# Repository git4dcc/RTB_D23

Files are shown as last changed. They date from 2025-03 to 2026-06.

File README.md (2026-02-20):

# RTB_D23




The D23 decoder is a double sided mobile decoder with 8-pol NEM 652 connector. The decoder is designed to integrate into the [RTB](https://rtb4dcc.de/concept/) digital control infrastructure.

<details>
<summary>See also</summary>

- [RTB_D12 - custom](/../../../../git4dcc/RTB_D12) (Fleischmann V100)
- [RTB_D13 - custom](/../../../../git4dcc/RTB_D13) (Minitrix coach)
- [RTB_D15 - custom](/../../../../git4dcc/RTB_D15) (Minitrix V160)
- [RTB_D16 - NEM651](/../../../../git4dcc/RTB_D16)
- [RTB_D20 - NEM651](/../../../../git4dcc/RTB_D20)
- [RTB_D21 - Next18](/../../../../git4dcc/RTB_D21)
- [RTB_D22 - Plux16](/../../../../git4dcc/RTB_D22)

</details>

<details>
<summary>User Guides</summary>

- User Guide - DE
- [User Guide - EN](https://rtb4dcc.de/rtb_decoder_reference_en/)

</details>

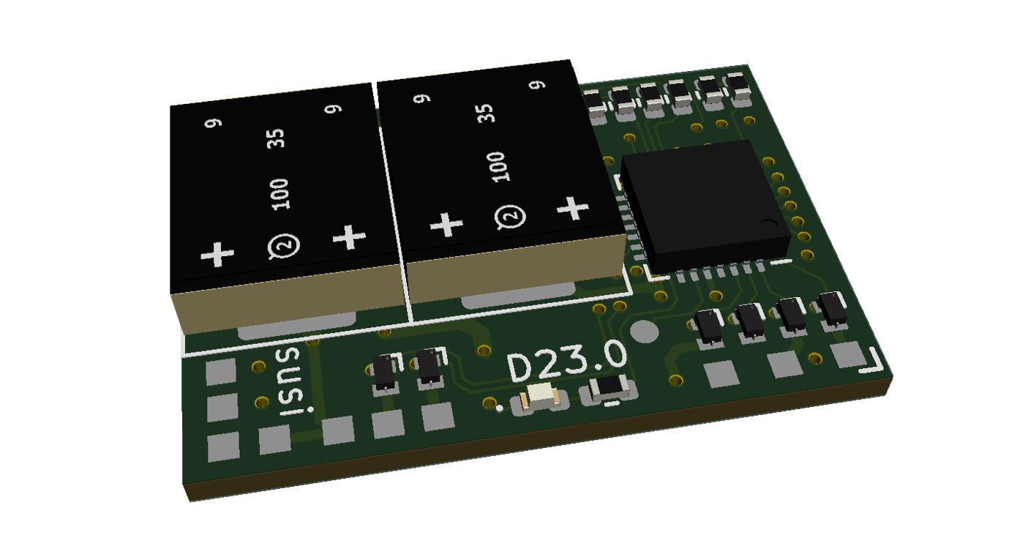
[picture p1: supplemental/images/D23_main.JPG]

<br>

## Decoder features,
- **NEM 652** connector
- **DCC**
  - DCC-A automatic logon
  - DCC-R protocol extension
  - Service Mode Programming
- **Railcom**
  - Channel 1/2
  - POM, xPOM
  - DYN: Speed, QoS, Track-voltage, Motor-current, AUX-current, Temp, Distance travelled
- Double sided
- Dimension: 19 x 12 mm
- 7-28V track voltage
- heartbeat LED
- adjustable max motor current (default 500mA)
- adjustable max AUX current (default 500mA)
- over temp protection
- Function output: LF/LR (dimmable, 1.4kHz) open drain
- Function output: AUX1 (dimmable, 1.4kHz) open drain via NEM 652 connector
- Function output: AUX2/AUX3/AUX4 open drain via solder pads
- Function output: AUX5/AUX6 logic level (3.3V) or ZBCLK/ZBDAT (3.3V)
- onboard buffer capacitor (2x 100uF/35V)
- <10mA idle power consumption
- Firmware update over main tracks via DCC-R protocol

# Hardware
The current PCB layout uses SMD footprints with 0.5mm pitch and 0402 parts. Reflow soldering is mandatory whereas handsoldering near to impossible.

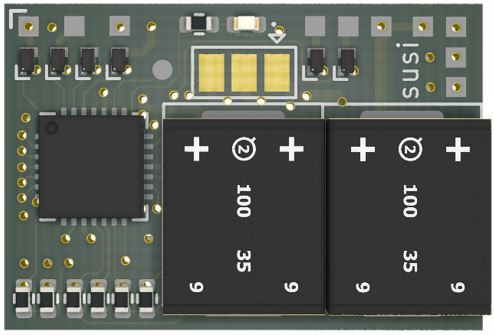
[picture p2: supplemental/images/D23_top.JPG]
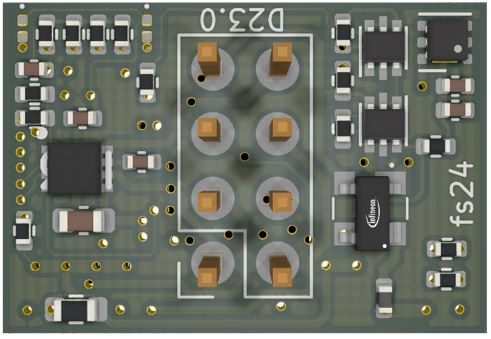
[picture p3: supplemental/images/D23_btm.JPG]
   

## PCB
- 6-layer PCB, FR4, 18 x 12 x 0.8mm (double sided)
- CPU: AVR64DD28
- Motor bridge: DRV8231

## Kicad
[Schematic](doc/D23_schematic.pdf) | [Layout](doc/D23_layout.pdf) | [Gerber](gerber)

<details>
<summary>Dependency</summary>
<br>

:yellow_circle: Requires my Kicad project library [RTB_SamacSys](/../../../../git4dcc/RTB_SamacSys) in the same directory tree.

</details>

## Firmware
Filename structure: { **pcb** }{ **code** }{ **version** }.hex

Example: **D23F0001**.hex

| | Description |
| --- | --- |
| **pcb** | Name of matching hardware (**D23**) |
| **code** | Type of code contained (**R**=rom, **B**=bootloader, **F**=flash, **U**=bld update, **P**=UPDI factory code) |
| **version** | Release version (**####**) |

[Firmware files](firmware)

## UPDI
The fuse settings as well as the P-code (D23Pxxxx.hex) has to be installed by using UPDI.<br>
Connecting the decoder via its track pins to a 5V(DC) power supply will boot its CPU. This way, its easy to program the fuses and flash.

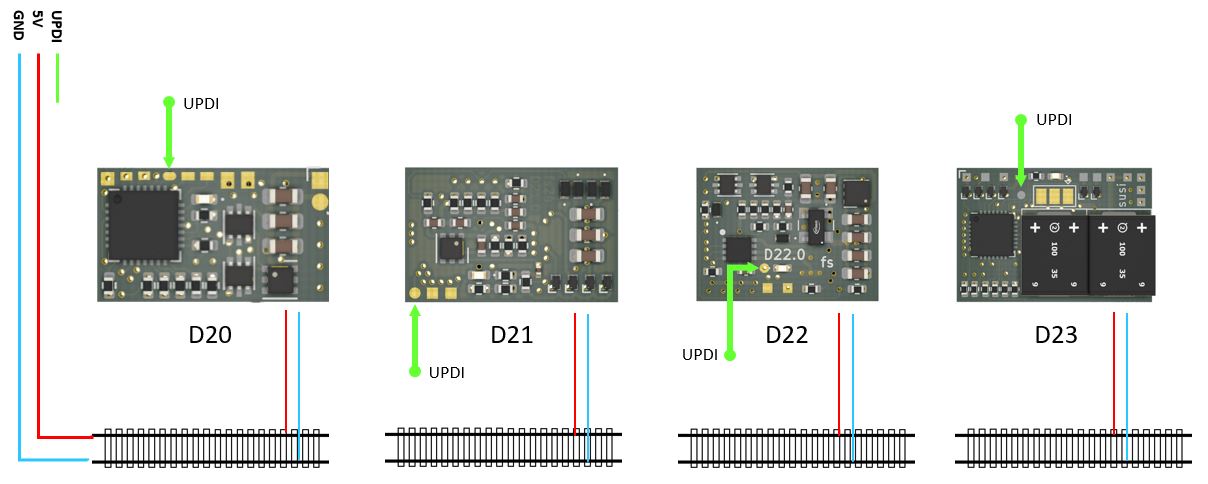
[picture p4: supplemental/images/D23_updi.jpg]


<details>
<summary>Details</summary>

| Fuse Setting | P-code Install |
| --- | --- |
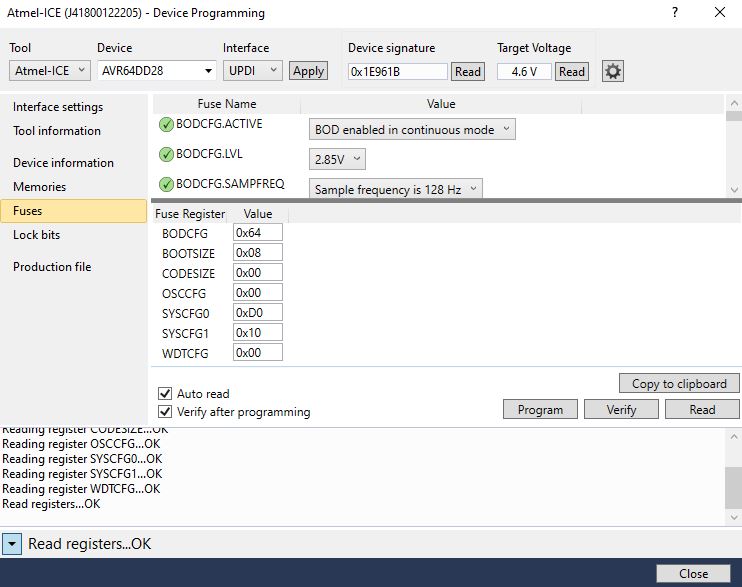
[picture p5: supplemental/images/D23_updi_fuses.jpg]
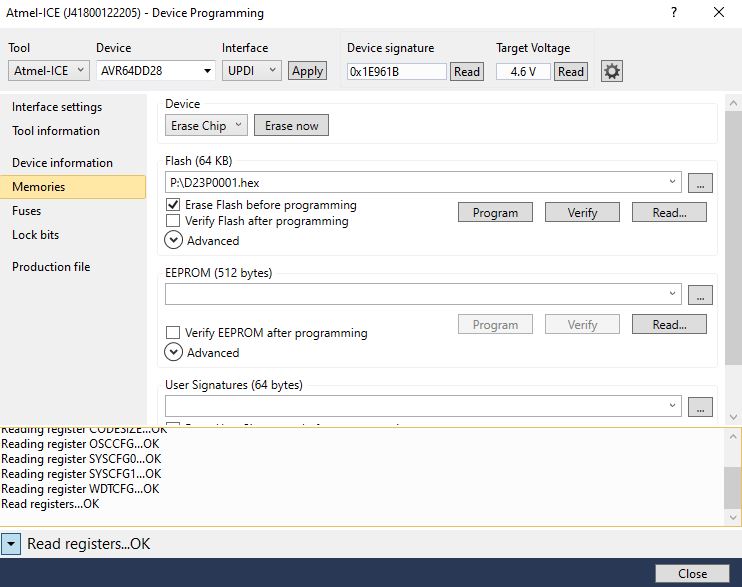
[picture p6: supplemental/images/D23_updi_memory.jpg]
|||

</details>

# Images
| top | bottom |
| --- | --- |
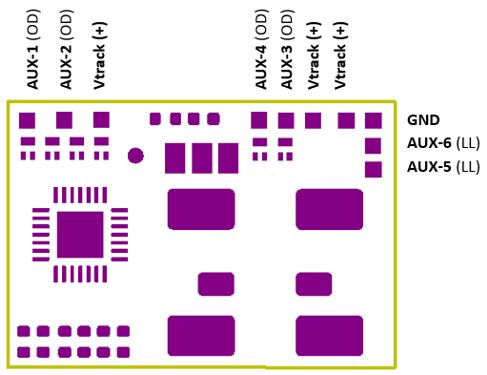
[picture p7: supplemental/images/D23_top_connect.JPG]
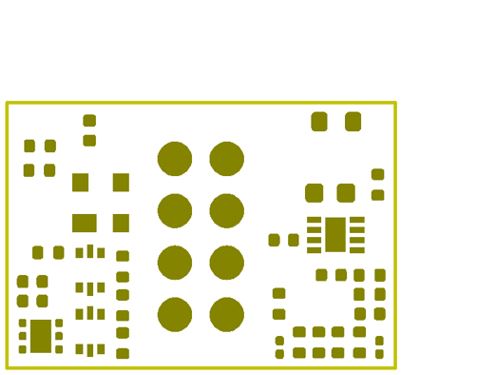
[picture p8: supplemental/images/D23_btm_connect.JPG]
|  |  |

# YouTube
Some YouTubes to see the D23 decoder in action.<br><br>
[](https://youtu.be/aH7pGpX5ZGo)
[](https://youtu.be/Ebl8b5DK1Gw)

This project is intended for hobby use only and is distributed in accordance with the Apache License 2.0 agreement.

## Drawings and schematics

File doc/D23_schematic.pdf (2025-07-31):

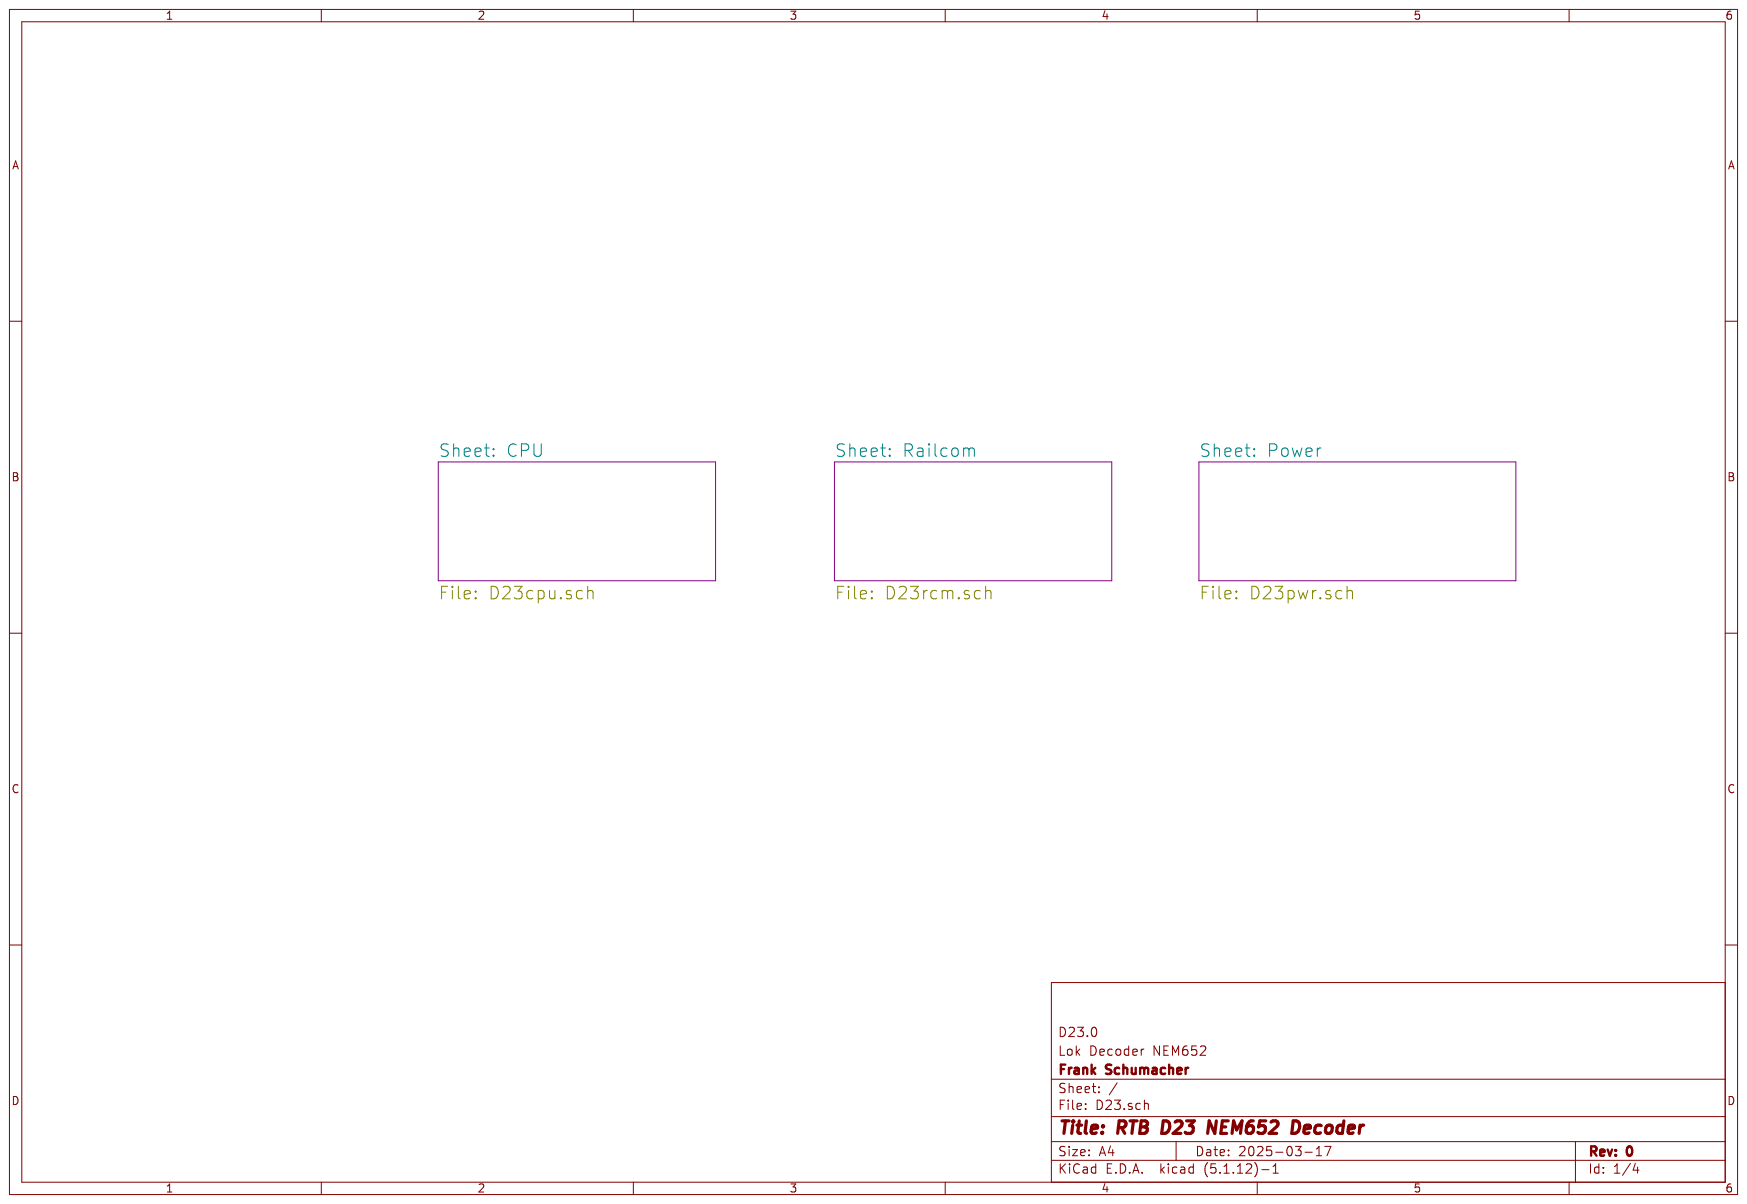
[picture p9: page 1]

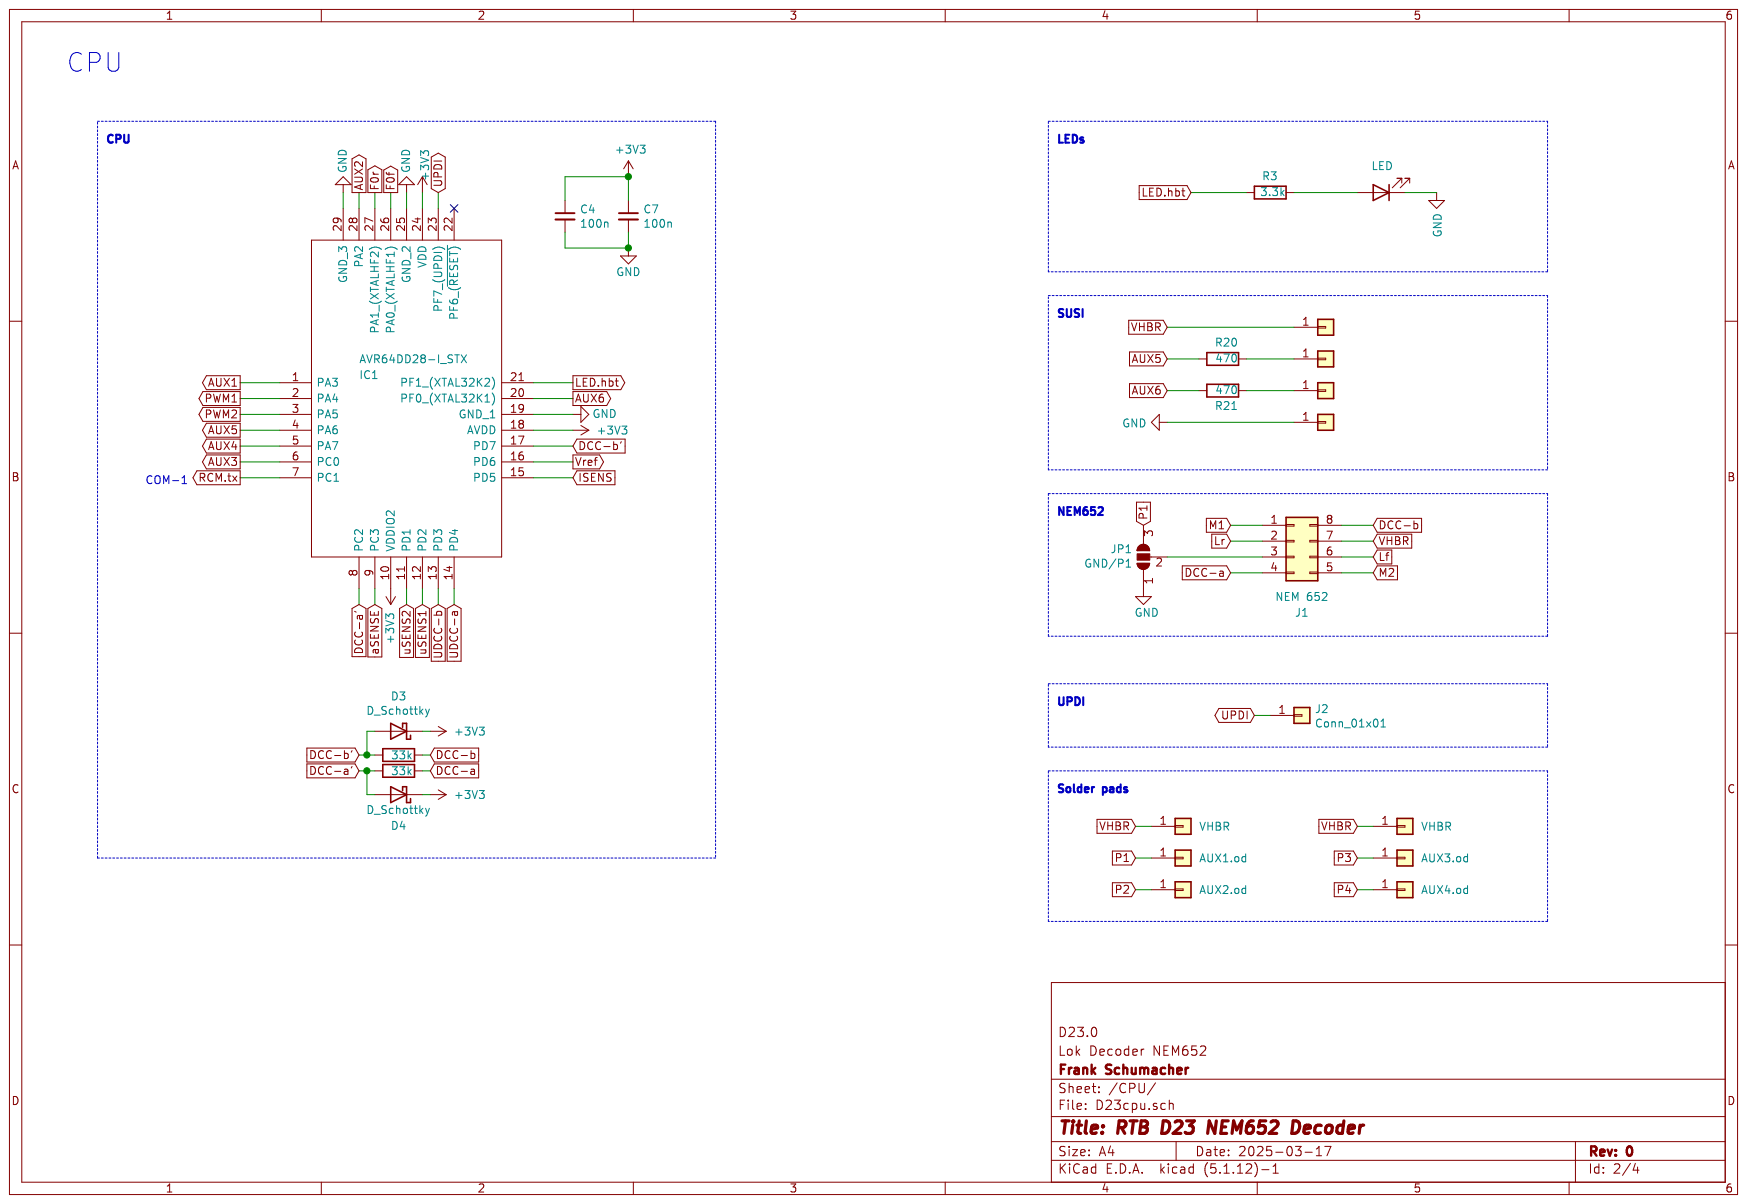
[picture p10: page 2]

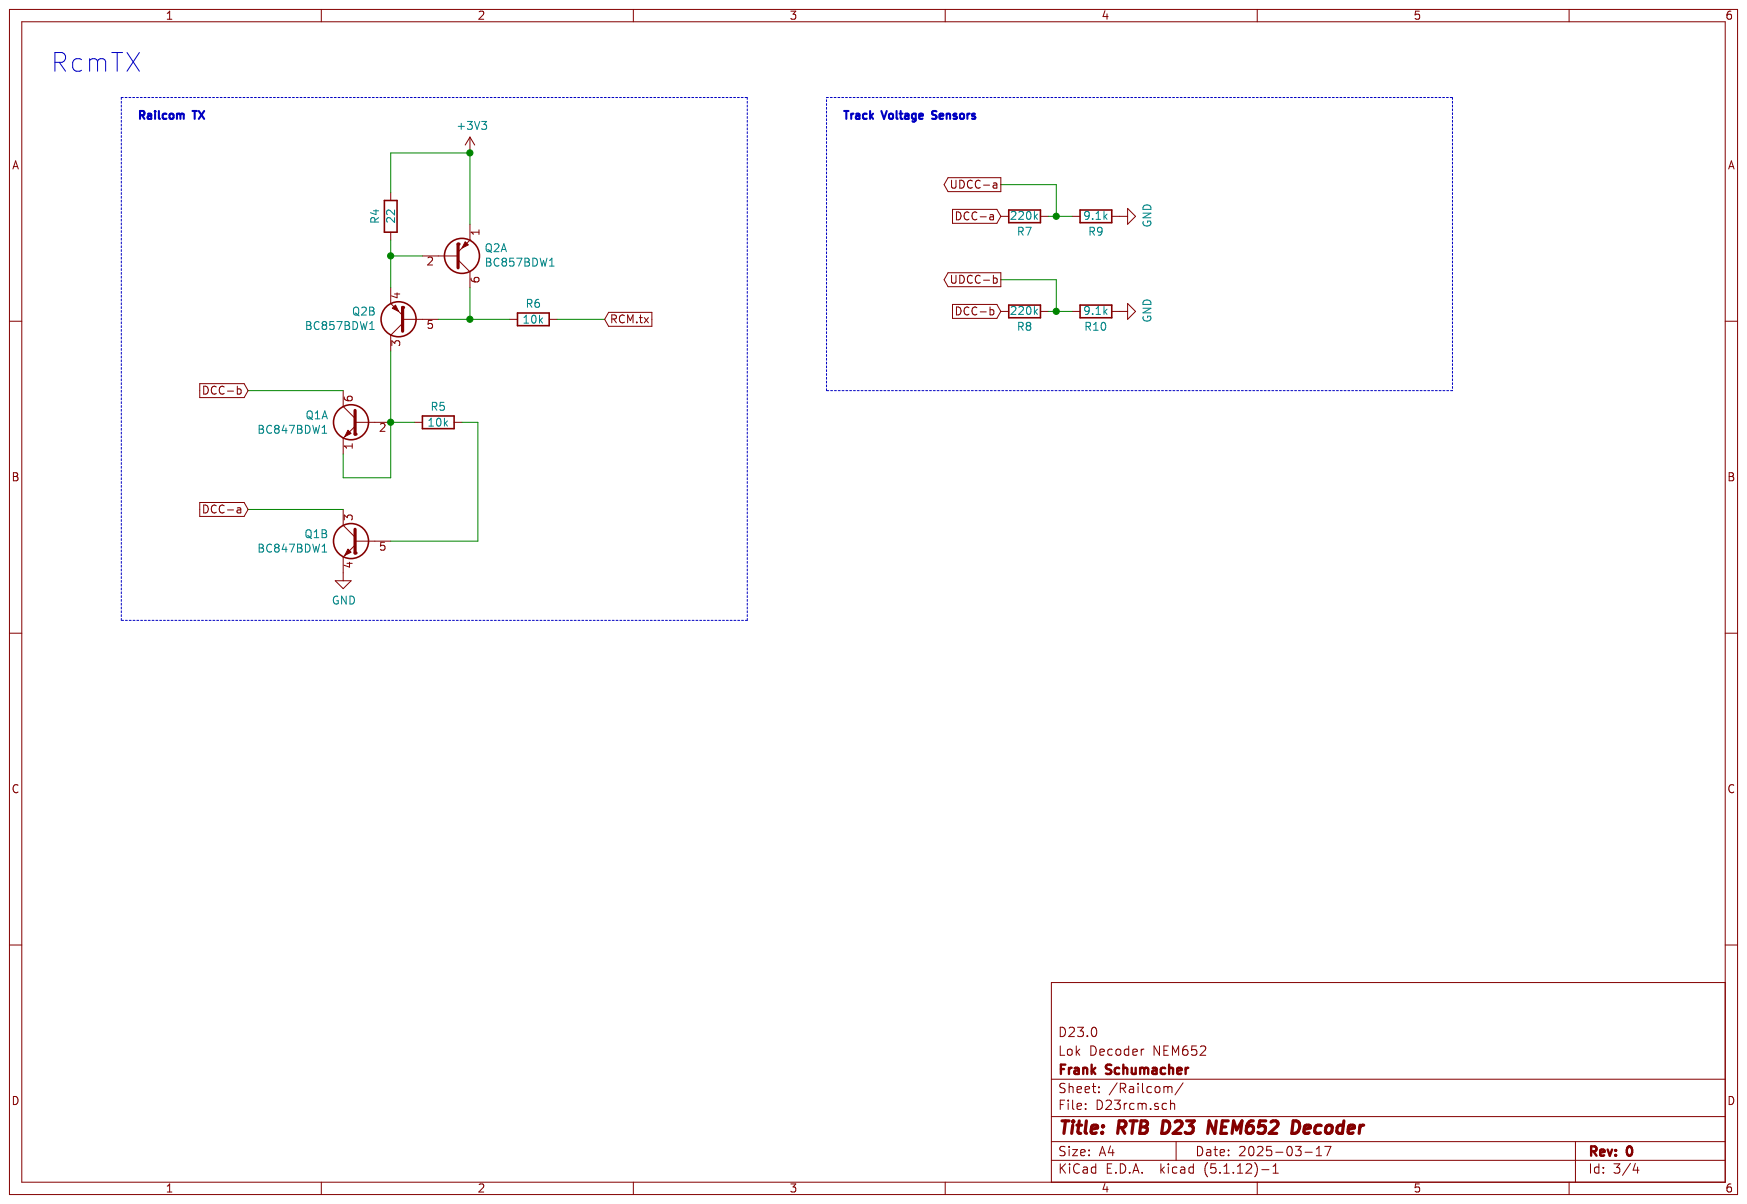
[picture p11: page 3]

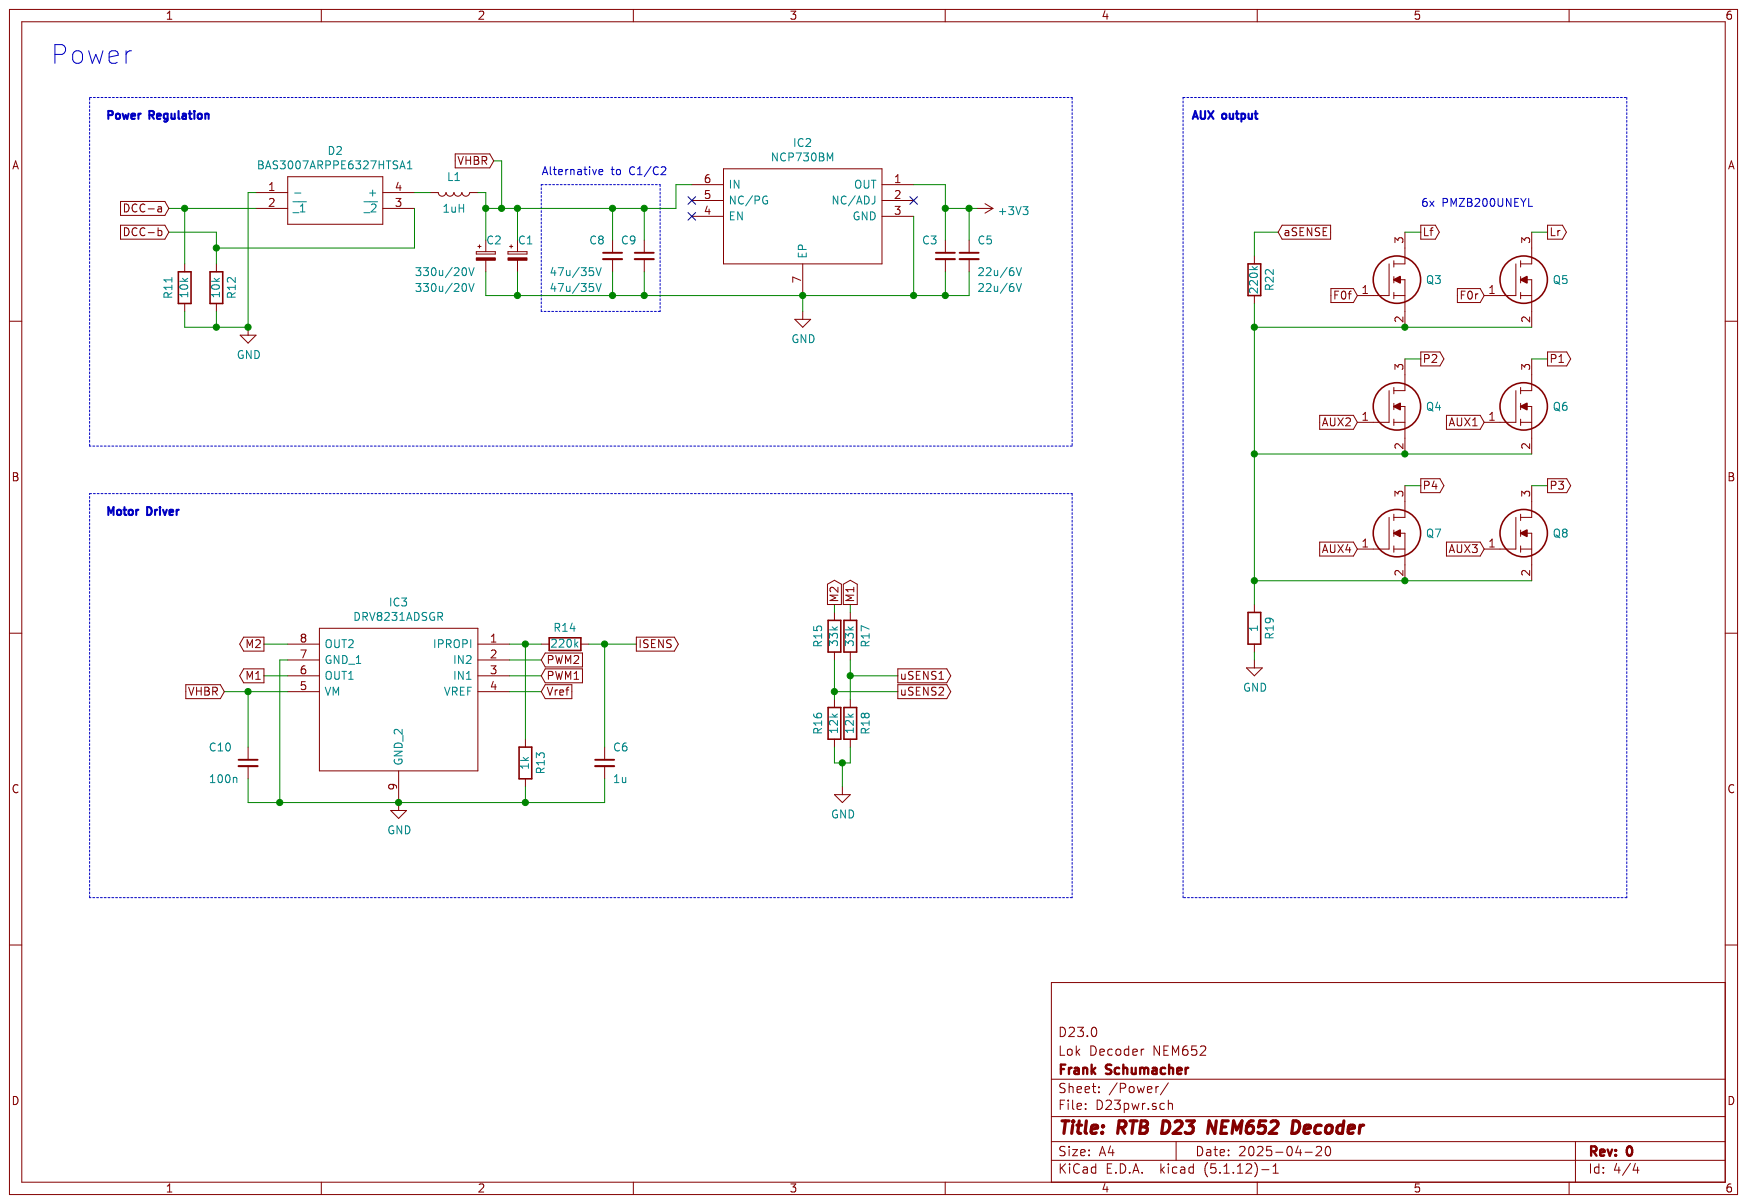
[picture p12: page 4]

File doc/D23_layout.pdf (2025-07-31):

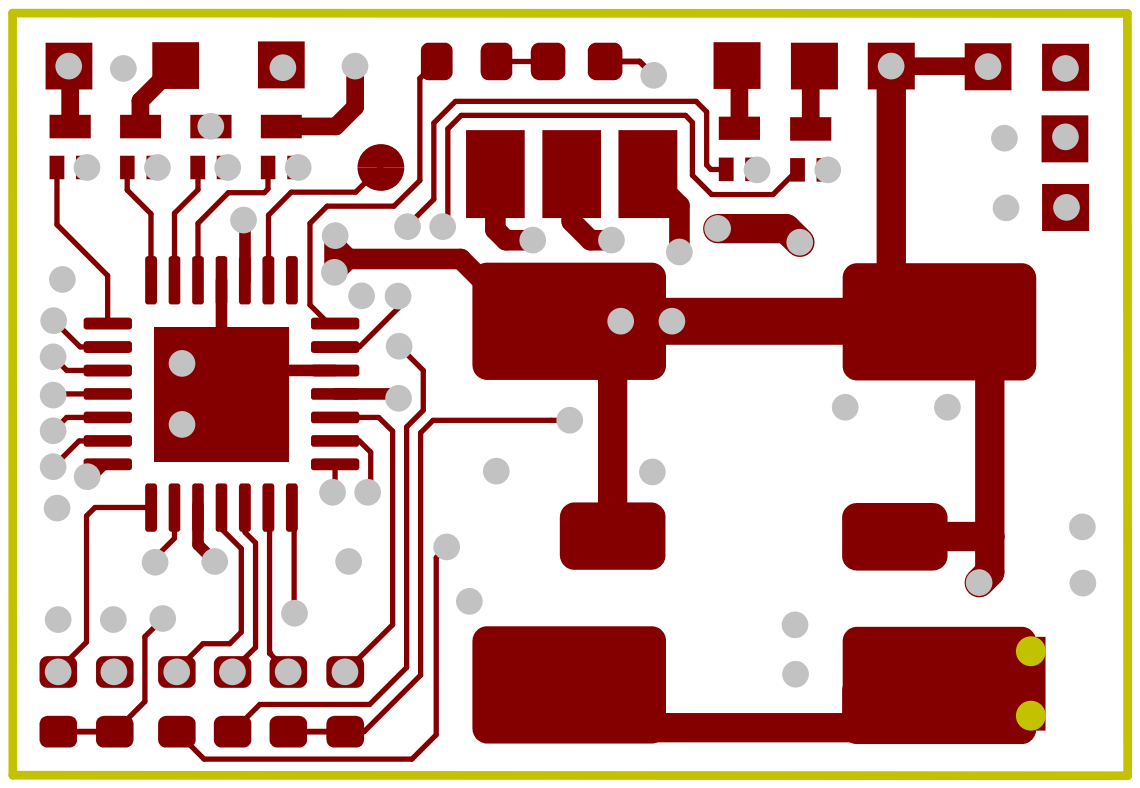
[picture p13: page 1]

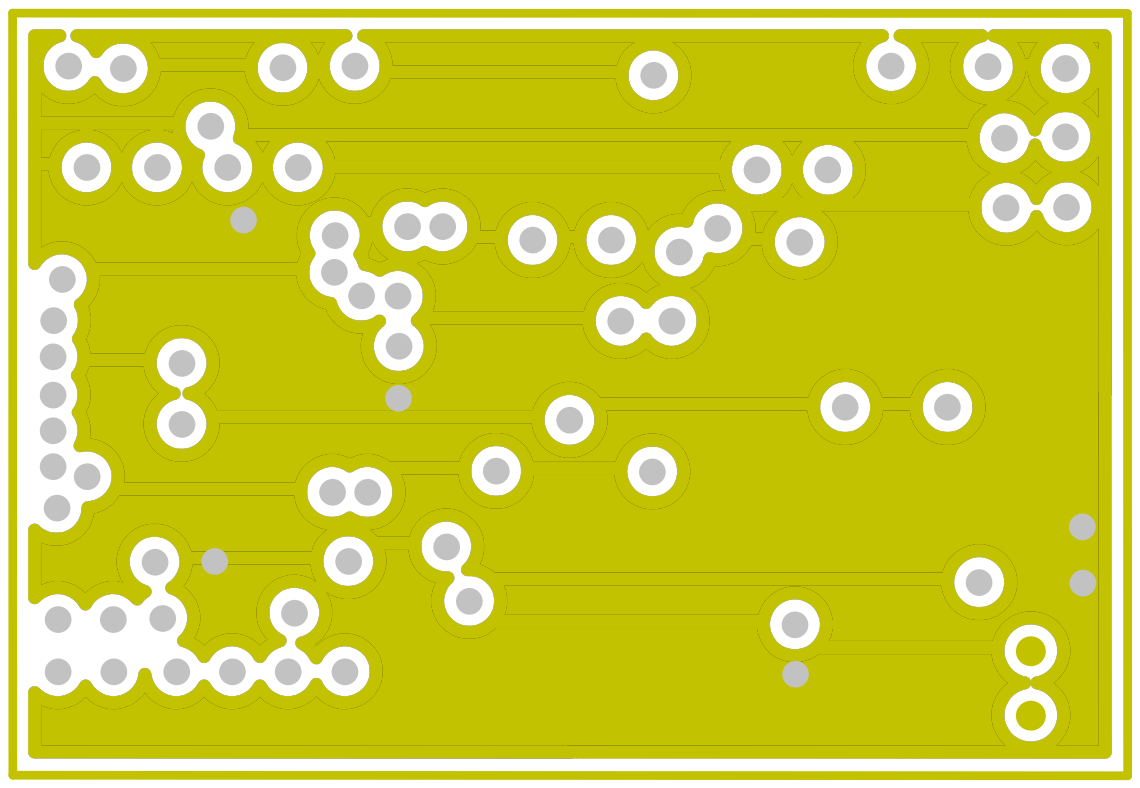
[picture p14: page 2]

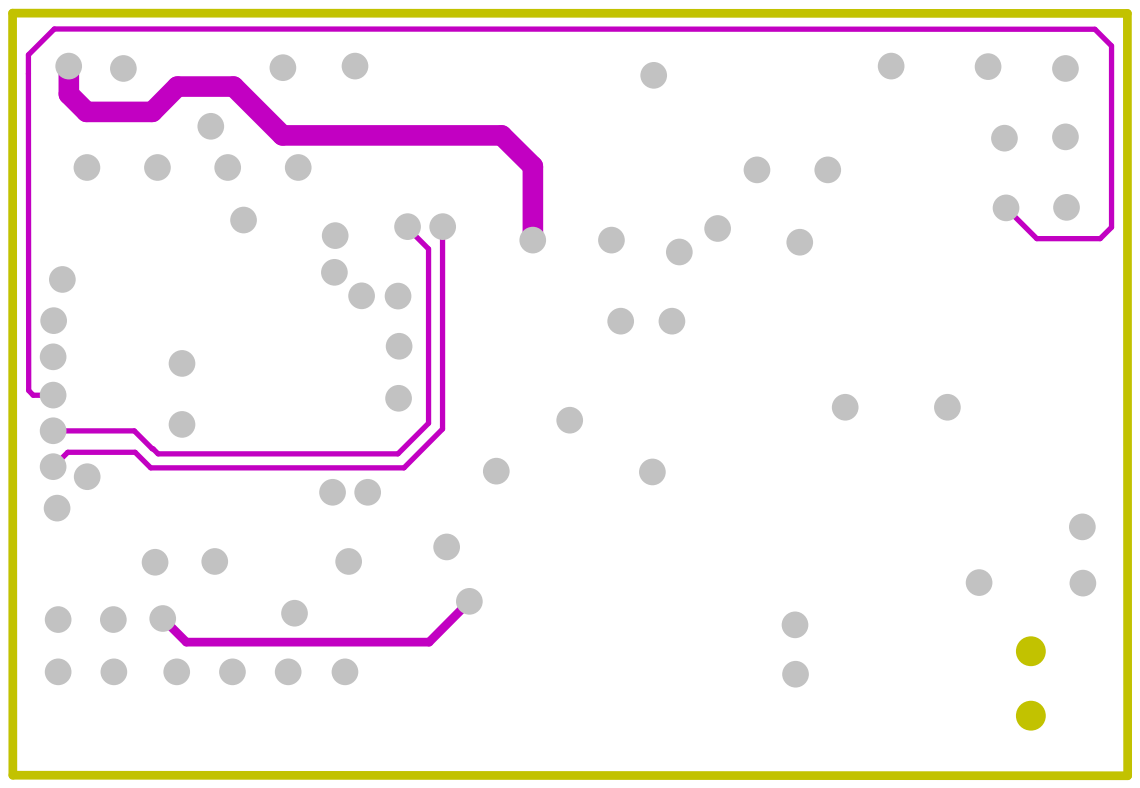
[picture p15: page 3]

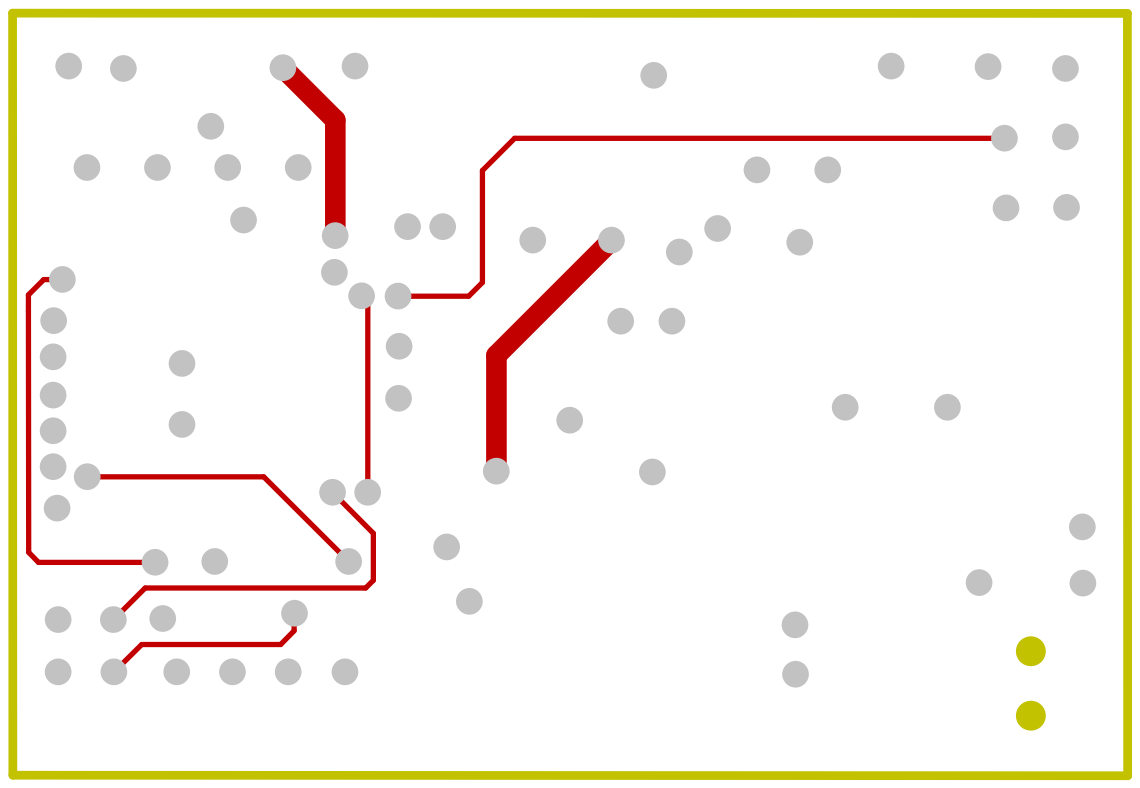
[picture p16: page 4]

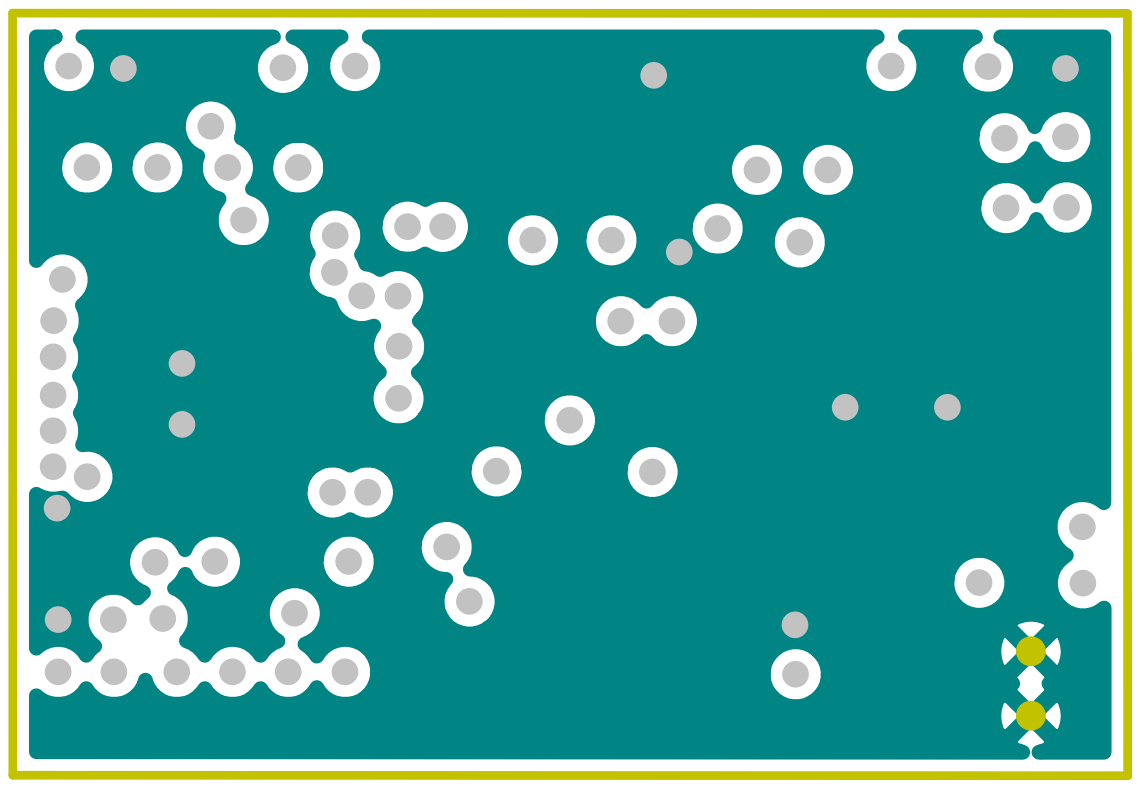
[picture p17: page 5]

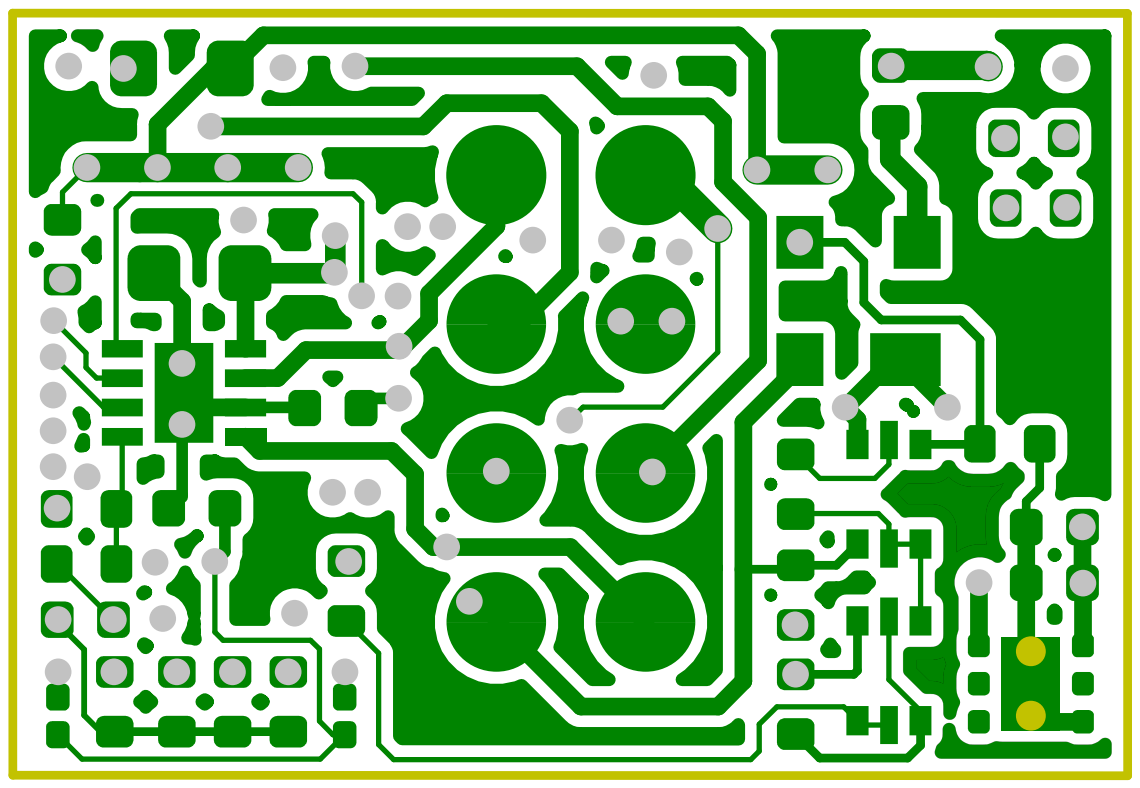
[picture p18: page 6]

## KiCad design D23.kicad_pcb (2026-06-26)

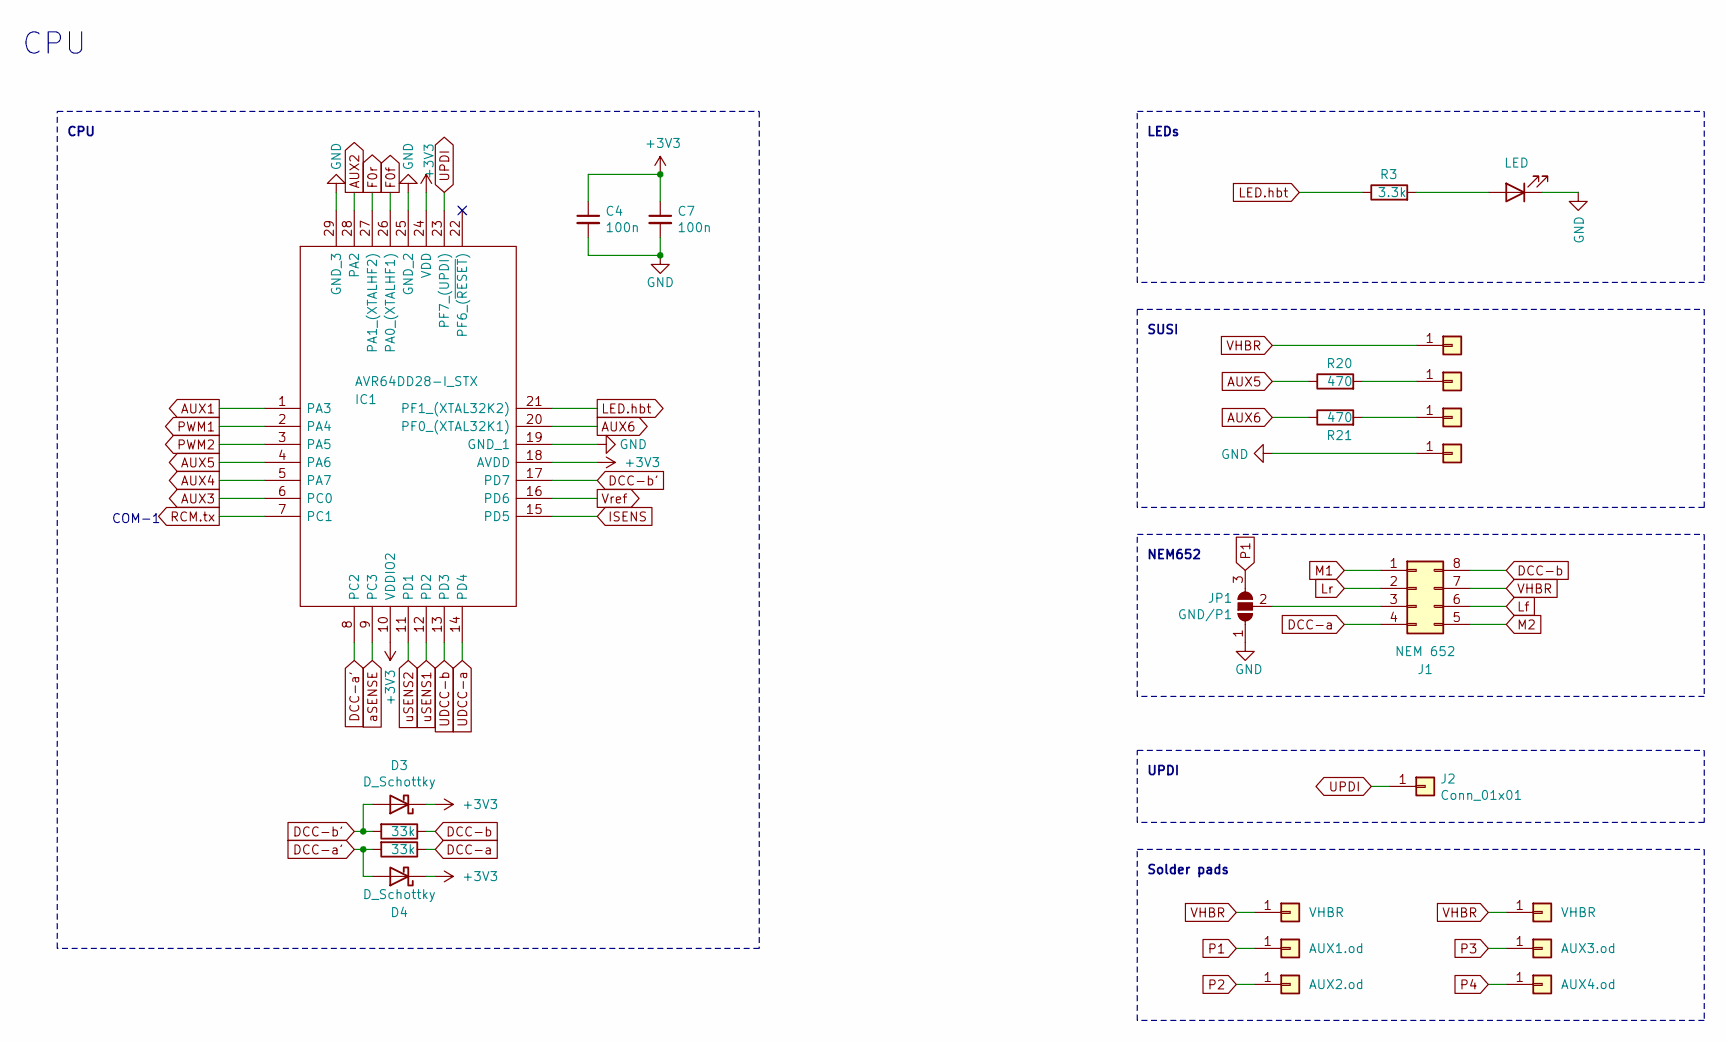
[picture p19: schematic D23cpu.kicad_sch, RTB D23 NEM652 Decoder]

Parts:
C4, C7: 100n; C_0402_1005Metric
D1: LED; LED_0402_1005Metric
D3, D4: D_Schottky; D_0201_0603Metric
IC1: AVR64DD28-I_STX; QFN-28-1EP_4x4mm_P0.4mm_EP2.3x2.3mm; Mouser Part Number 494-AVR64DD28-I/STX
J1: NEM 652; NEM-652
J2, J5, J6, J7, J11: Conn_01x01; DummyNet-Connector
J3: AUX1.od; DummyNet-Connector
J4: AUX2.od; DummyNet-Connector
J8, J12: VHBR; DummyNet-Connector
J9: AUX3.od; DummyNet-Connector
J10: AUX4.od; DummyNet-Connector
JP1: GND/P1; SolderJumper-3_P1.3mm_Open_Pad1.0x1.5mm
R1, R2: 33k; R_0402_1005Metric
R3: 3.3k; R_0402_1005Metric
R20, R21: 470; R_0402_1005Metric

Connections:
+3V3: C4.1, C7.1, D3.1 (K), D4.1 (K), IC1.10 (VDDIO2), IC1.18 (AVDD), IC1.24 (VDD); also elsewhere on the board
AUX1: IC1.1 (PA3); also elsewhere on the board
AUX2: IC1.28 (PA2); also elsewhere on the board
AUX3: IC1.6 (PC0); also elsewhere on the board
AUX4: IC1.5 (PA7); also elsewhere on the board
AUX5: IC1.4 (PA6), R20.1
AUX6: IC1.20 (PF0_(XTAL32K1)), R21.1
DCC-a: J1.4, R1.1; also elsewhere on the board
DCC-a': D4.2 (A), IC1.8 (PC2), R1.2
DCC-b: J1.8, R2.1; also elsewhere on the board
DCC-b': D3.2 (A), IC1.17 (PD7), R2.2
F0f: IC1.26 (PA0_(XTALHF1)); also elsewhere on the board
F0r: IC1.27 (PA1_(XTALHF2)); also elsewhere on the board
GND: C4.2, C7.2, D1.1 (K), IC1.19 (GND_1), IC1.25 (GND_2), IC1.29 (GND_3), J11.1, JP1.1 (A); also elsewhere on the board
ISENS: IC1.15 (PD5); also elsewhere on the board
LED.hbt: IC1.21 (PF1_(XTAL32K2)), R3.1
Lf: J1.6; also elsewhere on the board
Lr: J1.2; also elsewhere on the board
M1: J1.1; also elsewhere on the board
M2: J1.5; also elsewhere on the board
unnamed: D1.2 (A), R3.2
unnamed: J1.3, JP1.2 (C)
unnamed: J6.1, R20.2
unnamed: J7.1, R21.2
P1: J3.1, JP1.3 (B); also elsewhere on the board
P2: J4.1; also elsewhere on the board
P3: J9.1; also elsewhere on the board
P4: J10.1; also elsewhere on the board
PWM1: IC1.2 (PA4); also elsewhere on the board
PWM2: IC1.3 (PA5); also elsewhere on the board
RCM.tx: IC1.7 (PC1); also elsewhere on the board
UDCC-a: IC1.14 (PD4); also elsewhere on the board
UDCC-b: IC1.13 (PD3); also elsewhere on the board
UPDI: IC1.23 (PF7_(UPDI)), J2.1
VHBR: J1.7, J5.1, J8.1, J12.1; also elsewhere on the board
Vref: IC1.16 (PD6); also elsewhere on the board
aSENSE: IC1.9 (PC3); also elsewhere on the board
uSENS1: IC1.12 (PD2); also elsewhere on the board
uSENS2: IC1.11 (PD1); also elsewhere on the board

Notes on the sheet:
Solder pads
CPU
COM-1
LEDs
SUSI
NEM652
UPDI

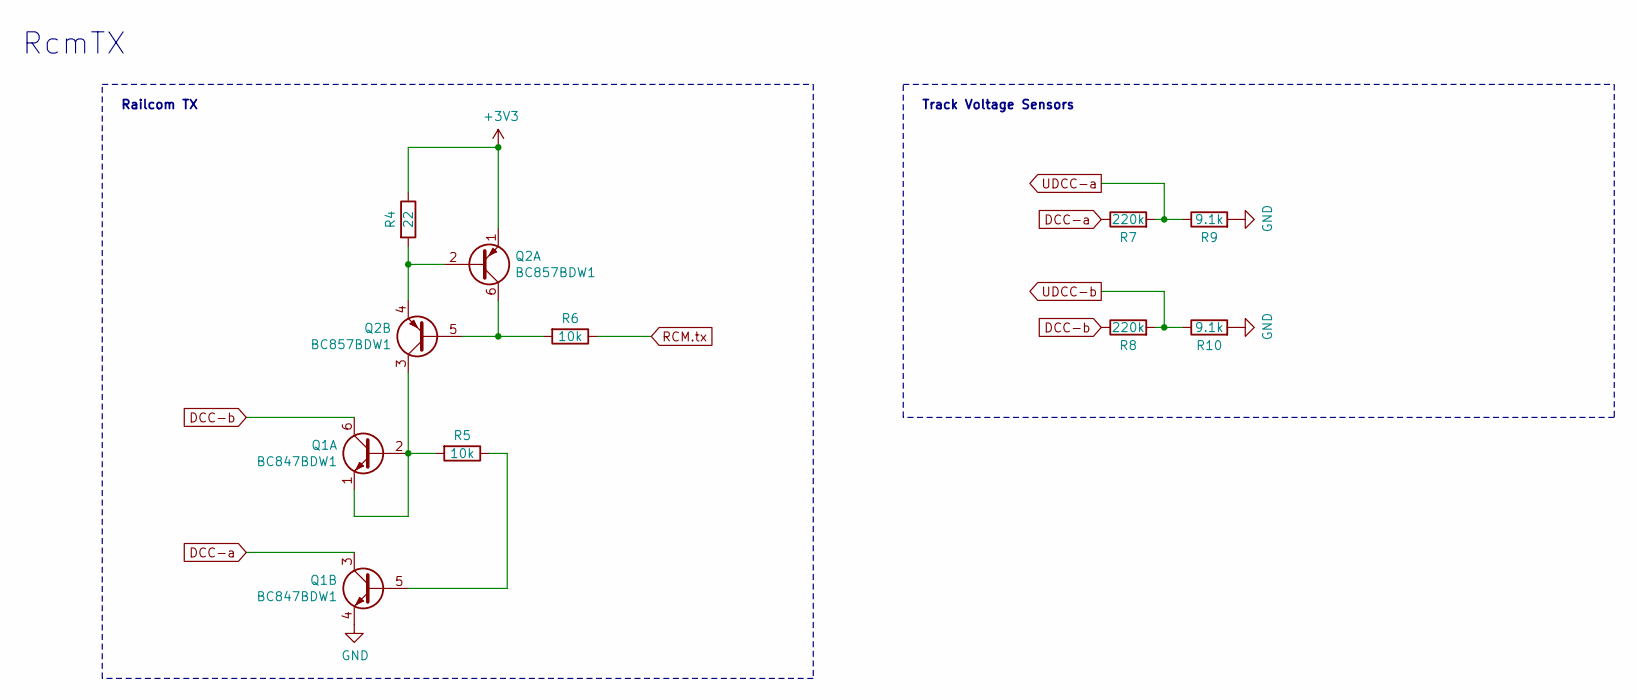
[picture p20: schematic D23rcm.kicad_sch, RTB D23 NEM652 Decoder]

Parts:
Q1: BC847BDW1; SOT-666
Q2: BC857BDW1; SOT-666
R4: 22; R_0402_1005Metric
R5, R6: 10k; R_0402_1005Metric
R7, R8: 220k; R_0402_1005Metric
R9, R10: 9.1k; R_0402_1005Metric

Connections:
+3V3: Q2.1 (E1), R4.1; also elsewhere on the board
DCC-a: Q1.3 (C2), R7.1; also elsewhere on the board
DCC-b: Q1.6 (C1), R8.1; also elsewhere on the board
GND: Q1.4 (E2), R9.2, R10.2; also elsewhere on the board
unnamed: Q1.1 (E1), Q1.2 (B1), Q2.3 (C2), R5.2
unnamed: Q1.5 (B2), R5.1
unnamed: Q2.2 (B1), Q2.4 (E2), R4.2
unnamed: Q2.5 (B2), Q2.6 (C1), R6.2
RCM.tx: R6.1; also elsewhere on the board
UDCC-a: R7.2, R9.1; also elsewhere on the board
UDCC-b: R8.2, R10.1; also elsewhere on the board

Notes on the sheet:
Track Voltage Sensors
Railcom TX
RcmTX

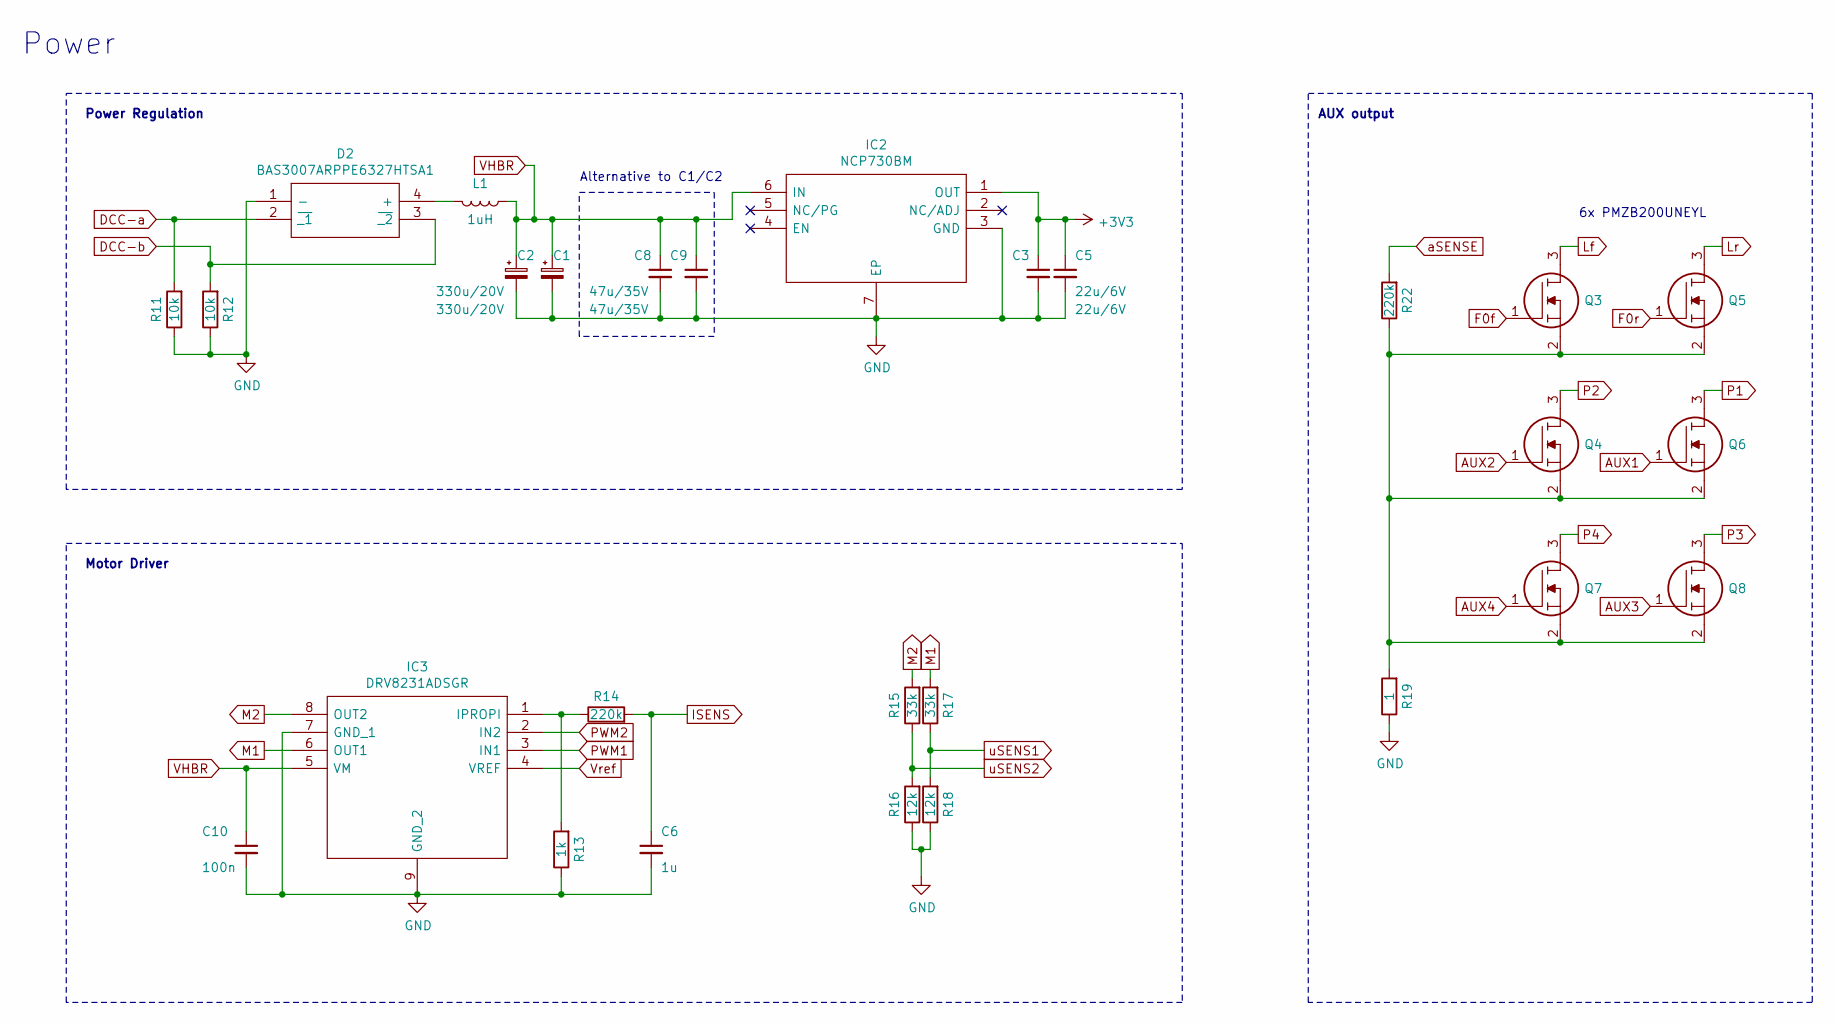
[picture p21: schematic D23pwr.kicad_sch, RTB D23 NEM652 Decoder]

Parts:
C1, C2: 330u/20V; CP_EIA-7361-438_AVX-U
C3, C5: 22u/6V; C_0402_1005Metric
C6: 1u; C_0402_1005Metric
C8, C9: 47u/35V; C_1206_3216Metric
C10: 100n; C_0603_1608Metric
D2: BAS3007ARPPE6327HTSA1; BF998215; Mouser Part Number 726-BAS3007A-RPPE6
IC2: NCP730BM; WSON-6-1EP_2x2mm_P0.65mm_EP1x1.6mm_ThermalVias; Mouser Part Number 863-NCP730BMT330TBG
IC3: DRV8231ADSGR; SON50P200X200X80-9N; Mouser Part Number 595-DRV8231ADSGR
L1: 1uH; L_0402_1005Metric
Q3, Q4, Q5, Q6, Q7, Q8: PMZB200UNEYL; Diodes_DFN1006-3; Mouser Part Number 771-PMZB200UNEYL
R11, R12: 10k; R_0402_1005Metric
R13: 1k; R_0402_1005Metric
R14, R22: 220k; R_0402_1005Metric
R15, R17: 33k; R_0402_1005Metric
R16, R18: 12k; R_0402_1005Metric
R19: 1; R_0603_1608Metric

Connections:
+3V3: C3.1, C5.1, IC2.1 (OUT); also elsewhere on the board
AUX1: Q6.1; also elsewhere on the board
AUX2: Q4.1; also elsewhere on the board
AUX3: Q8.1; also elsewhere on the board
AUX4: Q7.1; also elsewhere on the board
DCC-a: D2.2 (~_1), R11.2; also elsewhere on the board
DCC-b: D2.3 (~_2), R12.2; also elsewhere on the board
F0f: Q3.1; also elsewhere on the board
F0r: Q5.1; also elsewhere on the board
GND: C1.2, C2.2, C3.2, C5.2, C6.2, C8.2, C9.2, C10.2, D2.1 (-), IC2.3 (GND), IC2.7 (EP), IC3.7 (GND_1), IC3.9 (GND_2), R11.1, R12.1, R13.1, R16.1, R18.1, R19.1; also elsewhere on the board
ISENS: C6.1, R14.2; also elsewhere on the board
Lf: Q3.3; also elsewhere on the board
Lr: Q5.3; also elsewhere on the board
M1: IC3.6 (OUT1), R17.2; also elsewhere on the board
M2: IC3.8 (OUT2), R15.2; also elsewhere on the board
unnamed: D2.4 (+), L1.2
unnamed: IC3.1 (IPROPI), R13.2, R14.1
unnamed: Q3.2, Q4.2, Q5.2, Q6.2, Q7.2, Q8.2, R19.2, R22.1
P1: Q6.3; also elsewhere on the board
P2: Q4.3; also elsewhere on the board
P3: Q8.3; also elsewhere on the board
P4: Q7.3; also elsewhere on the board
PWM1: IC3.3 (IN1); also elsewhere on the board
PWM2: IC3.2 (IN2); also elsewhere on the board
VHBR: C1.1, C2.1, C8.1, C9.1, C10.1, IC2.6 (IN), IC3.5 (VM), L1.1; also elsewhere on the board
Vref: IC3.4 (VREF); also elsewhere on the board
aSENSE: R22.2; also elsewhere on the board
uSENS1: R17.1, R18.2; also elsewhere on the board
uSENS2: R15.1, R16.2; also elsewhere on the board

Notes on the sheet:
Motor Driver
Alternative to C1/C2
AUX output
Power Regulation
Power
6x PMZB200UNEYL

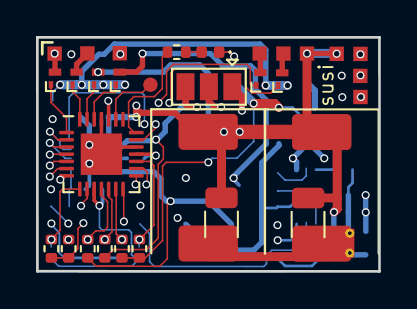
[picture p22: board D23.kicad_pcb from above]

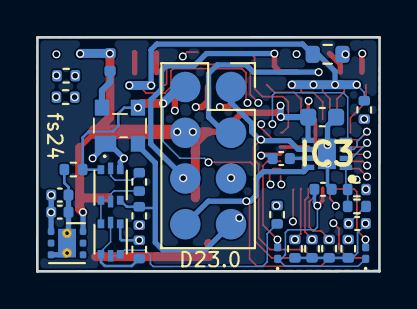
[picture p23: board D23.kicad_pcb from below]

Board: 6 copper layers, 19.0 x 13.0 mm, 61 parts (30 on the bottom side), 46 nets.

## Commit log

2025-07-31 add: fuses
    [D23.kicad_pcb, D23pwr.sch, D23rcm.sch]
2025-08-05 mod: led automation
2026-06-26 updated Kicad version
    [D23.kicad_pcb, D23.kicad_sch, D23cpu.kicad_sch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]
2026-07-09 mod: code cleanup
    [D23.sch, D23cpu.sch, D23pwr.sch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]
